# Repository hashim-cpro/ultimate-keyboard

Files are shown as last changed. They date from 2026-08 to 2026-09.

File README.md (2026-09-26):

# Ultimate-keyboard

A custom **75% (84-key)** mechanical keyboard built from the ground up with **Bluetooth 5.0 wireless & wired USB-C connectivity**, **individually addressable per-key RGB backlighting**, **Kailh MX hot-swap sockets**, and **integrated LiPo battery charging**.

It uses the [nrfmicro](https://github.com/joric/nrfmicro) microcontroller architecture as inspiration. Basically, instead of soldering a separate development board onto the keyboard, I copied the microcontroller schematics, put the **Nordic nRF52840 SoC** (via Ebyte E73 module) directly onto the keyboard's PCB, added battery charging and power management circuitry, and routed the entire PCB myself! At the end of the day, the IC lives right on the keyboard PCB with ample room to route everything cleanly.

---

## 3D Renders & Showcase

| Top View | Isometric Side View | Bottom View |
| :---: | :---: | :---: |
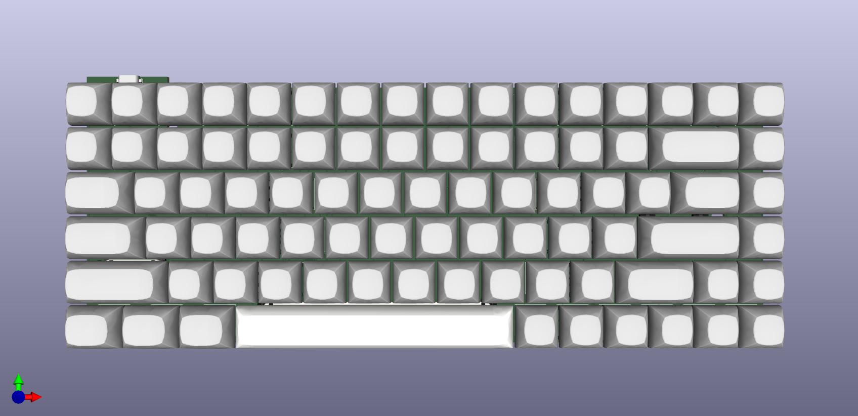
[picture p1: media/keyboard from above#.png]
Top View
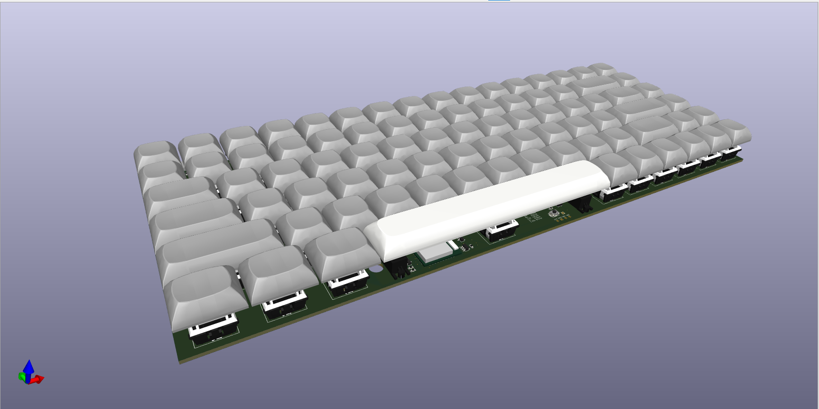
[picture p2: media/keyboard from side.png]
Side View
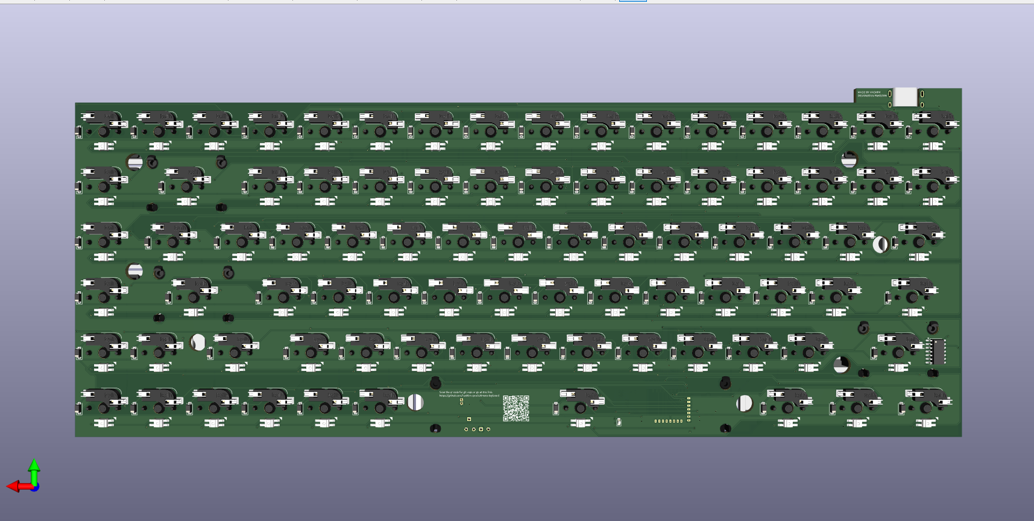
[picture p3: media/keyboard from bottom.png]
Bottom View
|  |  |  |

| PCB Top Layer | PCB Bottom Layer |
| :---: | :---: |
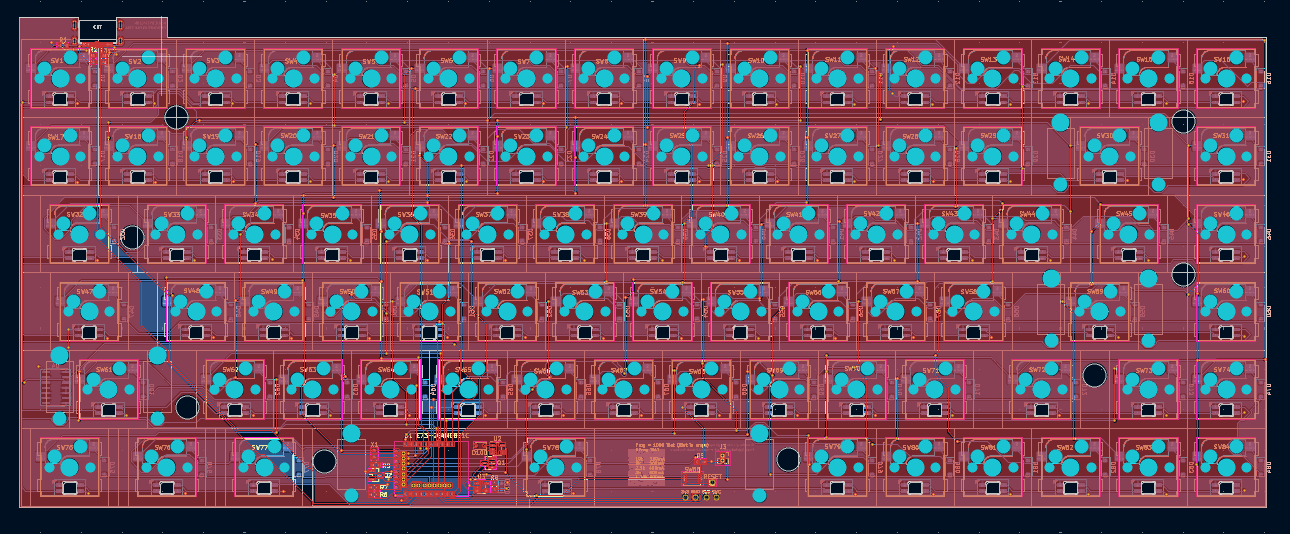
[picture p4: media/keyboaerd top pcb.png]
PCB Top
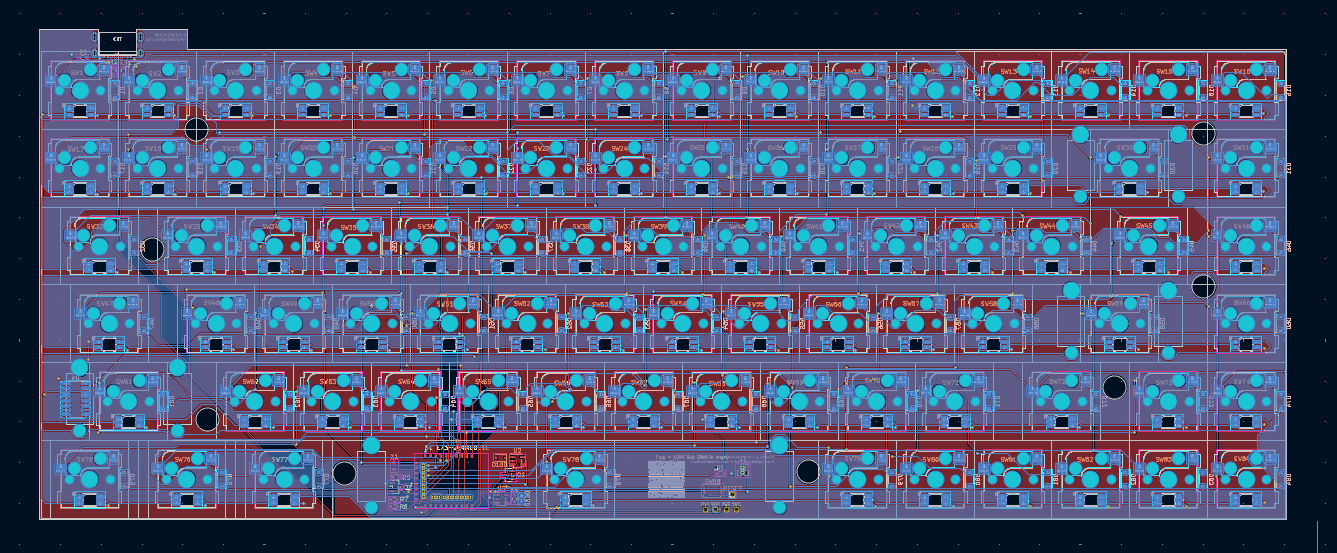
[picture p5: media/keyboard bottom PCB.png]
PCB Bottom
|  |  |

---

## Project Directory Map

```
ultimate-keyboard/
├── .github/
│   └── workflows/
│       └── build.yml               # Automated ZMK CI build workflow
├── boards/hashim/ultimate_keyboard/ # Zephyr HWMv2 board definition
│   ├── board.yml                   # Board metadata (SoC: nrf52840, variant: zmk)
│   ├── Kconfig.ultimate_keyboard   # Board selection & ZMK_BOARD_COMPAT
│   ├── Kconfig.defconfig           # Name & bootloader retention settings
│   ├── ultimate_keyboard.zmk.yml   # ZMK hardware metadata catalog
│   ├── ultimate_keyboard_nrf52840_zmk.dts # Devicetree definition (matrix, ADC, SPI RGB)
│   └── ultimate_keyboard_nrf52840_zmk_defconfig # Base Kconfig drivers
├── config/
│   ├── ultimate_keyboard.keymap    # 84-key QWERTY + Function layers
│   ├── ultimate_keyboard.conf      # Bluetooth TX power, sleep, RGB underglow
│   └── west.yml                    # Manifest
├── firmware/
│   ├── boards/hashim/ultimate_keyboard/ # Board definition mirror
│   ├── config/                     # Keymap and config mirror
│   ├── build.yaml                  # Firmware build matrix
│   └── ultimate_keyboard.uf2       # Compiled functional flash file (ready to flash)
├── hardware/
│   ├── nrfmicro.kicad_sch
│   ├── nrfmicro.kicad_pcb
│   ├── nrfmicro.kicad_pro
├── exports/
│   ├── gerbers.zip
│   └── others/
│       ├── nrfmicro.csv
│       ├── nrfmicro.step
│       └── nrfmicro board.step
├── media/
├── build.yaml
├── keyboard-layout.json
├── upper plate.dxf
├── journal.md
└── README.md
```

---

## Bill of Materials (BOM)

### 1. Integrated Circuits & Semiconductors

| Designator | Value / Part | Package / Footprint | Qty | Description |
| :--- | :--- | :--- | :-: | :--- |
| U1 | **[E73-2G4M08S1C](https://www.ebyte.com/en/product-view-news.html?id=445)** | E73-2G4M08S1C-52840 |  1  | Nordic nRF52840 Bluetooth 5.0 & USB 2.0 SoC Module with PCB Antenna |
| U2 | **[AP2112K-3.3](https://lcsc.com/product-detail/Low-Dropout-Regulators-LDO_Diodes-Incorporated-AP2112K-3-3TRG1_C51118.html)** | SOT-23-5 |  1  | 3.3V 600mA Ultra-Low Dropout (LDO) Linear Voltage Regulator |
| U3 | **[TP4054](https://lcsc.com/product-detail/Battery-Management-ICs_TP4054_C32574.html)** | SOT-23-5 |  1  | Standalone Linear Li-Ion Battery Charger IC |
| U4 | **[74AHCT125](https://lcsc.com/product-detail/Buffers-Drivers-Receivers-Transceivers_Nexperia-74AHCT125D-118_C137151.html)**  | SOIC-14 (3.9x8.7mm, P1.27mm) |  1  | Quad Buffer / 3.3V to 5V Logic Level Shifter for RGB LEDs |
| Q1, Q2 | **[AO3407](https://lcsc.com/product-detail/MOSFETs_Alpha-Omega-Semicon-AO3407_C13184.html)** | SOT-23 |  2  | P-Channel 30V MOSFET (Power path switching & battery reverse protection) |
| D100 | **[1N5819](https://lcsc.com/product-detail/Schottky-Barrier-Diodes-SBD_1N5819W_C169344.html)** | D_SOD-323F |  1  | Schottky Barrier Rectifier Diode (Power OR-ing) |
| D200 | **RED LED** | LED_0603_1608Metric |  1  | Red 0603 SMD LED (Battery charge indicator) |

### 2. Key Matrix Diodes & Addressable RGB LEDs

| Designator | Value / Part | Package / Footprint | Qty | Description |
| :--- | :--- | :--- | :-: | :--- |
| D1 – D84 | **[1N4148WT](https://lcsc.com/product-detail/Switching-Diodes_1N4148W_C2128.html)** | D_SOD-123 | 84  | High-Speed Switching Diodes (Anti-Ghosting / NKRO Matrix) |
| LED1 – LED84 | **[SK6812MINI-E](https://lcsc.com/product-detail/Light-Emitting-Diodes-LED_HOUEN-SK6812MINI-E_C2890035.html)** | MX_SK6812MINI-E_REV | 84  | Reverse-Mount Individually Addressable RGB LEDs |

### 3. Kailh MX Hot-Swap Sockets

| Designator | Key Size | Footprint |  Qty | Target Keys |
| :--- | :---: | :--- | :----: | :--- |
| SW2, SW29, ... | **[1.00u Socket](https://www.aliexpress.com/w/wholesale-kailh-hot-swap-socket.html)** | SW_Hotswap_Kailh_MX_1.00u | 73 | Standard 1u Alpha, Number, Function & Navigation keys |
| SW75, SW76, SW77  | **1.25u Socket** | SW_Hotswap_Kailh_MX_1.25u | 3 | Left Ctrl, Left Win, Left Alt |
| SW45, SW32 | **1.50u Socket** | SW_Hotswap_Kailh_MX_1.50u | 2 | Tab, Backslash (\|) |
| SW47, SW72 | **1.75u Socket** | SW_Hotswap_Kailh_MX_1.75u | 2 | Caps Lock, Right Shift |
| SW30 | **2.00u Socket** | SW_Hotswap_Kailh_MX_2.00u | 1 | Backspace |
| SW59, SW61 | **2.25u Socket** | SW_Hotswap_Kailh_MX_2.25u | 2 | Left Shift, Enter |
| SW78 | **6.25u Socket** | SW_Hotswap_Kailh_MX_6.25u | 1 | Spacebar |
| **Total Sockets** | | | **84** | Full 75% layout coverage |

### 4. Connectors, Switches & Crystal

| Designator | Value / Part | Package / Footprint | Qty | Description |
| :--- | :--- | :--- | :-: | :--- |
| J1 | **[USB-C Receptacle 16-pin](https://lcsc.com/product-detail/USB-Connectors_SHOU-HAN-TYPE-C-16PIN_C319133.html)** | USB-C_C168688 |  1  | USB Type-C Receptacle (16-Pin) |
| J2 | **Conn_01x04** | connector_swd |  1  | 4-Pin SWD Header (VDD, SWDIO, SWCLK, GND) |
| J3 | **Conn_01x02** | PinSocket_1x02_P1.27mm_Vertical |  1  | 2-Pin Battery Header (for LiPo battery) |
| SW85 | **[Tactile Switch](https://lcsc.com/product-detail/Tactile-Switches_ALPS-ALPINE-SKRK-series_C2665793.html)** | SW_Push_SPST_NO_Alps_SKRK |  1  | Tactile Push Button (Reset / Bootloader mode) |
| RESET | **TestPoint** | TestPoint_THTPad_1.0x1.0mm_Drill0.5mm |  1  | Hardware Reset Test Point |
| X1 | **[32.768kHz Crystal](https://lcsc.com/product-detail/Crystals_Micro-Crystal-Switzerland-CM9V-T1A-32-768kHz-7pF-20PPM-TA-QC_C347311.html)** | CM9V-T1A-2Pin_1.6x1.0mm |  1  | MicroCrystal CM9V-T1A low-frequency crystal for BLE sleep mode |

### 5. Resistors (SMD 0603)

| Designator | Value | Footprint | Qty | Function / Notes |
| :--- | :---: | :--- | :-: | :--- |
| R1 | **100kΩ** | R_0603_1608Metric |  1  | Pull-up / Gate bias resistor |
| R2, R3 | **5.1kΩ** | R_0603_1608Metric |  2  | USB Type-C CC1 / CC2 pull-down resistors (5V host negotiation) |
| R5 | **RPROG** | R_0603_1608Metric |  1  | Charge current setting resistor for TP4054 |
| R6 | **820kΩ** | R_0603_1608Metric |  1  | Voltage divider bias resistor |
| R7, R9 |  **2MΩ**  | R_0603_1608Metric |  2  | High-impedance battery voltage monitoring divider |
| R8 |  **1kΩ**  | R_0603_1608Metric |  1  | Current limiting resistor for indicator LED |

---

## Wiring Diagram

Completed wiring diagram
see in [pdf](/exports/diagrams/keyboard_wiring_diagram.pdf)

## Schematics

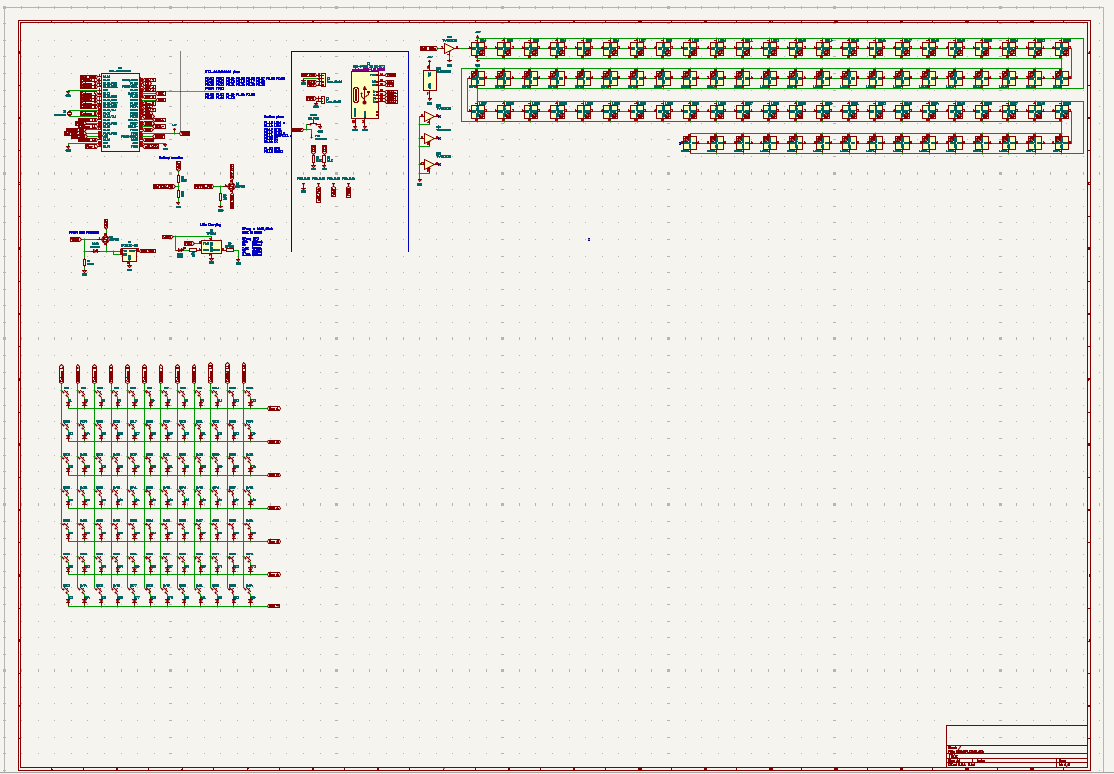
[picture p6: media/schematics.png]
Completed Schematic


## Firmware (ZMK)

The keyboard runs native [ZMK Firmware](https://zmk.dev/) built on the Zephyr RTOS with full support for Bluetooth Low Energy 5.0, USB HID, low-power deep sleep, battery level telemetry, and individually addressable RGB backlighting.

A pre-compiled, tested, ready-to-flash binary is available at: **[`firmware/ultimate_keyboard.uf2`](firmware/ultimate_keyboard.uf2)**

## How to Build the Firmware

### GitHub Actions (Recommended & Automated)

This repository includes a GitHub Actions workflow in [`.github/workflows/build.yml`](.github/workflows/build.yml) configured with ZMK's official build matrix. Every push to `main` automatically triggers a build in the cloud.

1. Edit your keymap in [`config/ultimate_keyboard.keymap`](config/ultimate_keyboard.keymap) or settings in [`config/ultimate_keyboard.conf`](config/ultimate_keyboard.conf).
2. Commit and push your changes:
3. Once the workflow run completes, click into the run, scroll to **Artifacts**, and download `ultimate_keyboard.zip`.
4. Extract the `.uf2` file and flash it!
   > (enter bootloader mode by holding the dedicated button beneath space bar)

---

## Assembly

After getting the PCB and the components, you can assemble the keyboard by following these steps:

- first of all solder the MCU and the ICs surrounding it on the top side of the PCB with a heat gun.
- then solder the usbc port and the boot button and the battery connections header(you can solder the wires directly to the pads if you want).
- then solder the diodes, rgb leds and switch sockets along with everything remaining on the bottom side of the PCB.
- connect the battery, flash the firmware, put the switches in and then you can test the keyboard and make sure everything is working properly.

---

### AI Usage Declaration

I used AI for research, general queries and for asking question like using it instead of google, and formatting the markdown documentation and BOM tables. and fixing firmware as well.

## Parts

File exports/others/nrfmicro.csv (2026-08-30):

Id | Designator | Footprint | Quantity | Designation | Supplier and ref
1 | RESET | TestPoint_THTPad_1.0x1.0mm_Drill0.5mm | 1 | TestPoint
2 | J2 | connector_swd | 1 | Conn_01x04
3 | SW85 | SW_Push_SPST_NO_Alps_SKRK | 1 | SW_Push
4 | X1 | Crystal_SMD_MicroCrystal_CM9V-T1A-2Pin_1.6x1.0mm_HandSoldering | 1 | 32768kHz
5 | U3 | SOT-23-5 | 1 | TP4054
6 | LED39,LED18,LED61,LED21,LED58,LED48,LED5,LED14,LED80,LED63,LED74,LED6,LED1,LED81,LED43,LED12,LED57,LED44,LED2,LED79,LED62,LED41,LED17,LED69,LED68,LED76,LED46,LED28,LED23,LED24,LED9,LED33,LED55,LED4,LED38,LED82,LED70,LED11,LED19,LED15,LED47,LED10,LED50,LED84,LED8,LED42,LED7,LED20,LED49,LED71,LED75,LED66,LED34,LED65,LED59,LED54,LED31,LED30,LED35,LED26,LED25,LED27,LED67,LED83,LED22,LED78,LED72,LED16,LED3,LED53,LED32,LED56,LED60,LED37,LED36,LED29,LED45,LED52,LED51,LED77,LED13,LED40,LED64,LED73 | MX_SK6812MINI-E_REV | 84 | SK6812MINI-E
7 | R8 | R_0603_1608Metric | 1 | 1K
8 | SW2,SW29,SW9,SW4,SW21,SW53,SW74,SW13,SW41,SW5,SW63,SW10,SW1,SW39,SW79,SW70,SW48,SW43,SW35,SW34,SW66,SW26,SW71,SW40,SW62,SW56,SW44,SW38,SW27,SW67,SW64,SW3,SW82,SW80,SW81,SW23,SW42,SW18,SW46,SW28,SW19,SW8,SW11,SW33,SW65,SW51,SW17,SW36,SW37,SW57,SW83,SW25,SW50,SW6,SW68,SW20,SW31,SW84,SW55,SW22,SW58,SW14,SW24,SW73,SW16,SW69,SW60,SW7,SW54,SW12,SW15,SW52,SW49 | SW_Hotswap_Kailh_MX_1.00u | 73 | SW_Push_45deg
9 | SW45,SW32 | SW_Hotswap_Kailh_MX_1.50u | 2 | SW_Push_45deg
10 | R5 | R_0603_1608Metric | 1 | RPROG
11 | Q2,Q1 | SOT-23 | 2 | AO3407
12 | SW47,SW72 | SW_Hotswap_Kailh_MX_1.75u | 2 | SW_Push_45deg
13 | R6 | R_0603_1608Metric | 1 | 820K
14 | SW75,SW77,SW76 | SW_Hotswap_Kailh_MX_1.25u | 3 | SW_Push_45deg
15 | U2 | SOT-23-5 | 1 | AP2112K-3.3
16 | J1 | USB-C_C168688 | 1 | USB-C USB 2.0 MC-372
17 | R3,R2 | R_0603_1608Metric | 2 | 5.1K
18 | SW59,SW61 | SW_Hotswap_Kailh_MX_2.25u | 2 | SW_Push_45deg
19 | R9,R7 | R_0603_1608Metric | 2 | 2M
20 | R1 | R_0603_1608Metric | 1 | 100K
21 | SW30 | SW_Hotswap_Kailh_MX_2.00u | 1 | SW_Push_45deg
22 | U1 | E73-2G4M08S1C-52840 | 1 | E73-2G4M08S1C
23 | J3 | PinSocket_1x02_P1.27mm_Vertical | 1 | Conn_01x02
24 | D100 | D_SOD-323F | 1 | 1N5819
25 | SW78 | SW_Hotswap_Kailh_MX_6.25u | 1 | SW_Push_45deg
26 | D16,D39,D62,D11,D68,D49,D75,D61,D69,D83,D55,D72,D44,D53,D27,D36,D4,D43,D9,D21,D30,D19,D17,D66,D48,D22,D10,D58,D84,D38,D82,D79,D52,D13,D54,D41,D45,D47,D35,D3,D80,D51,D29,D6,D81,D28,D23,D24,D57,D26,D64,D37,D63,D70,D1,D32,D25,D74,D12,D34,D77,D71,D8,D15,D5,D78,D18,D50,D40,D60,D14,D67,D33,D73,D7,D20,D2,D31,D76,D46,D59,D42,D56,D65 | D_SOD-123 | 84 | 1N4148WT
27 | U4 | SOIC-14_3.9x8.7mm_P1.27mm | 1 | 74AHCT125
28 | D200 | LED_0603_1608Metric | 1 | RED

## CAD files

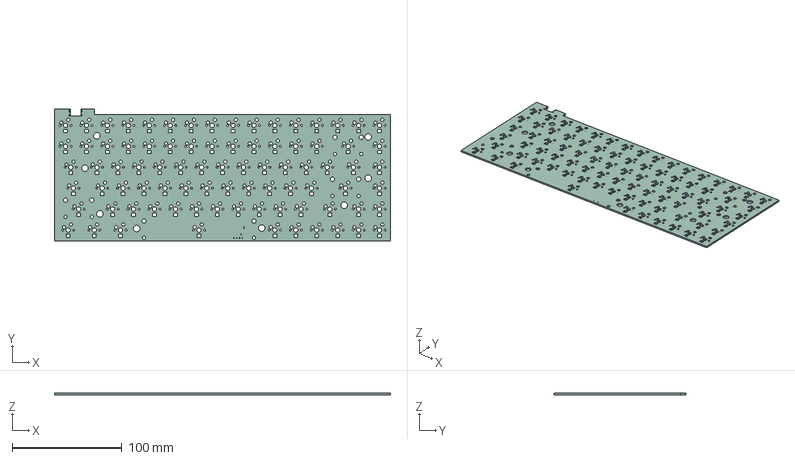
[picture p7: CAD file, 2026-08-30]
exports/others/nrfmicro board.step
305.8 x 120.2 x 1.51 mm

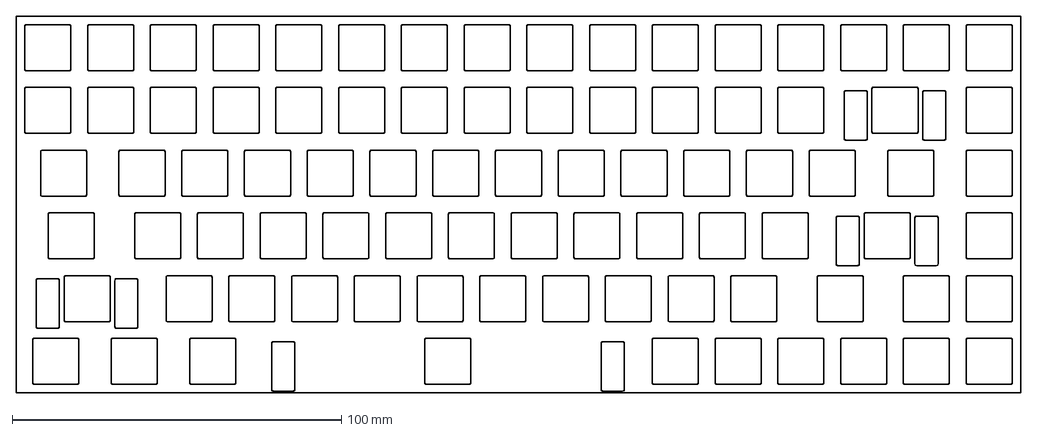
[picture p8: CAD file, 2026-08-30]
upper plate.dxf
304.8 x 114.3 mm

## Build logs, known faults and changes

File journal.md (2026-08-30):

---
title: "ultimate keyboard"
author: "Hashim"
description: "Dev journal for designing the ultimate 84-key wireless mechanical keyboard with onboard nRF52840, hot-swap sockets, and per-key RGB."
created_at: "July 8, 2026"
software: "KiCad, FreeCAD, ZMK"
---

# July 21: Researching for the ultimate keyboard

So i did some researching and basically what i want from this keyboard is a couple of things.

- has to be wireless
- needs to have multiple device connectivity and instant switching between them
- needs to have a good battery life
- hot swappable keys
- indiviidualy addressable RGB lghting

First thing that i want to do is decide the microcontroller for it supported by ZMK. ZMK could support basically any mcrocontroller that has the supporte microchip set but they recommended using some open source microcontrollers that are supported by the community. I took a look at some and decided why use a prebuilt microcontroller and why not just use the opensource microcontroller's schematics and put em on my keyboard and we would have ample PCB space because a keyboard is pretty big so why not just expand the microcontroller on the keyboard itself, what i am saying is use the microcontroller's schematics and put it on the keyboard's PCB and route it myself and place the components where ever i want to.

the microcontroller i choosed is [this](https://github.com/joric/nrfmicro):

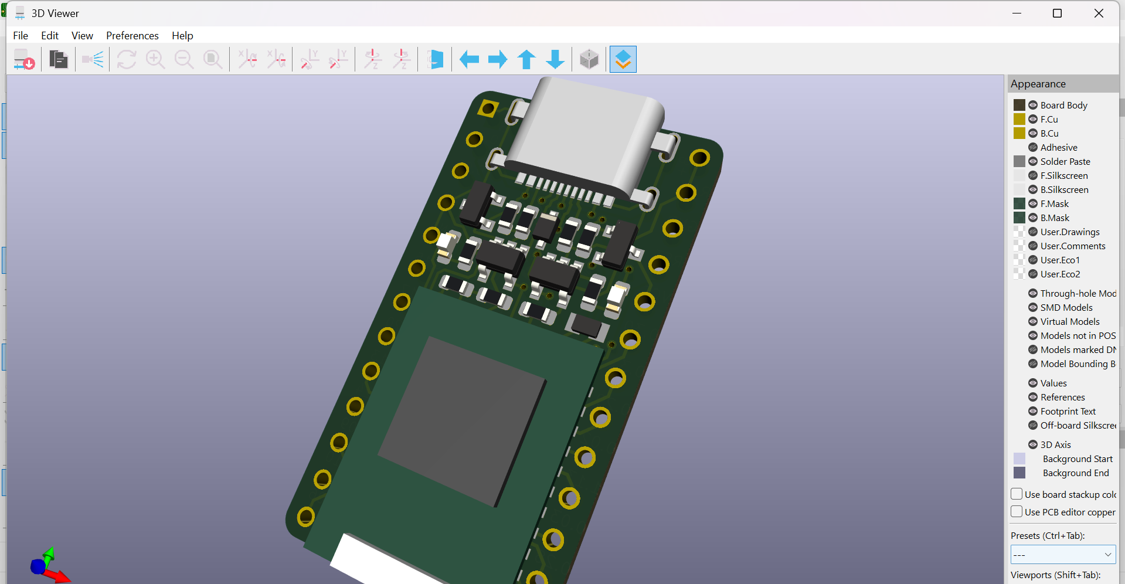
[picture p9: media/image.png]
nRFMicro Pinout


ok so started working on it, i would have a 84 keys keyboard. i first made the switch matrix closer to the actual shape of the keyboard layout but then somehow though we might not enough pins so ended up reverting it to this(but turns out we have more then enough pins, 28 to be precise)

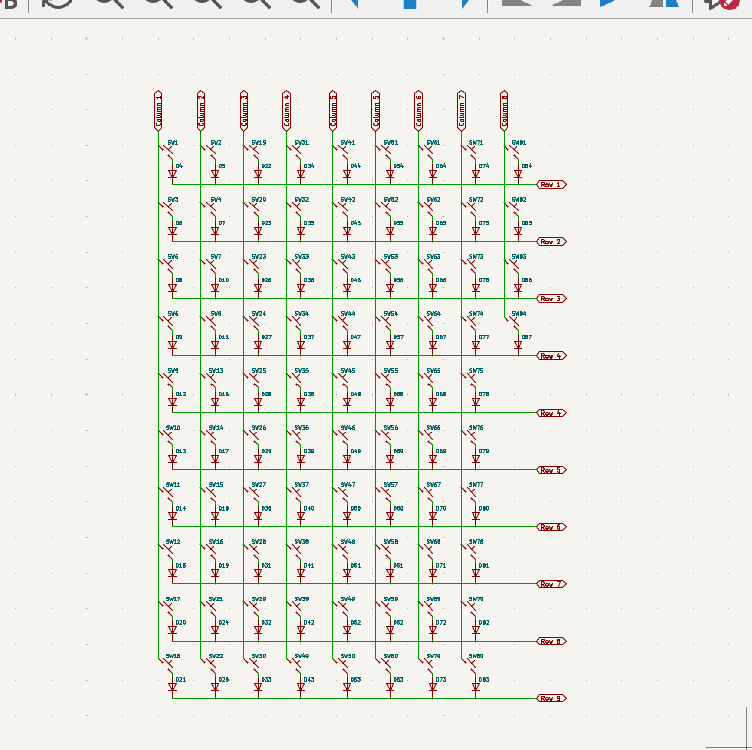
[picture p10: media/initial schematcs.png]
Initial Switch Matrix Schematic


Lapse session: https://lapse.hackclub.com/timelapse/6FpUl1i0e8Nd

---

# Next day: Footprints, 3D Models & Schematics

i finished the schematics, and found and imported all the footrpints and their 3d models and placed them on the PCB exactly where i wanted them to be.

Completed Keyboard Schematics

Lapse link:
https://lapse.hackclub.com/timelapse/ch_FO-Pfzgz0

---

# Next day: PCB Routing

i started routing the PCB, and it was a bit of a challenge because i had to route the microcontroller's pins to the switch matrix and also to the other components like the battery, charging circuit, and RGB lighting. But after a few hours of routing, i managed to get everything connected properly.

| Top PCB Routing | Bottom PCB Routing |
|:---:|:---:|
| Keyboard Top PCB | Keyboard Bottom PCB |

Lapse link:
https://lapse.hackclub.com/timelapse/OkOtTtODVTxe

---

# Next day: Mounting Holes & Bootloader Circuitry

added mounting holes, remaining stuff added related to bootloader and frmware flashing
i added circuitry for the bootloading thing and added a button for it

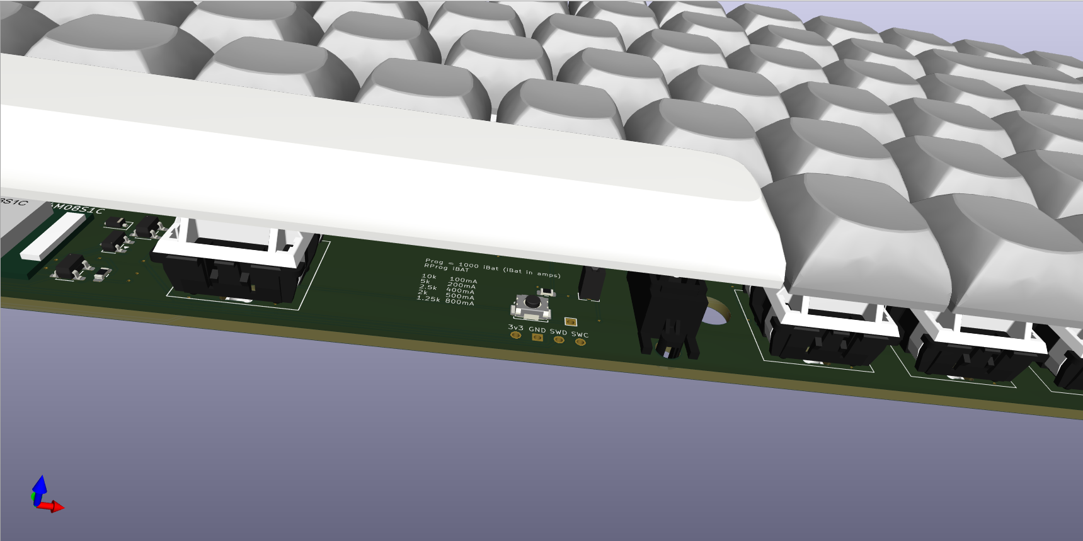
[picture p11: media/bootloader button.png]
Bootloader and Reset Button Circuitry


Lapse link:
https://lapse.hackclub.com/timelapse/6yTGAWsrufwA

---

# Next day: Case Modeling & Optimization

tried to start making a case
file was apparently too big and had to do a lot of isolations and optimization to keep it from crashing on my 4 gb ipad
so i just thought i show here what's that was made and make the case a separate project.

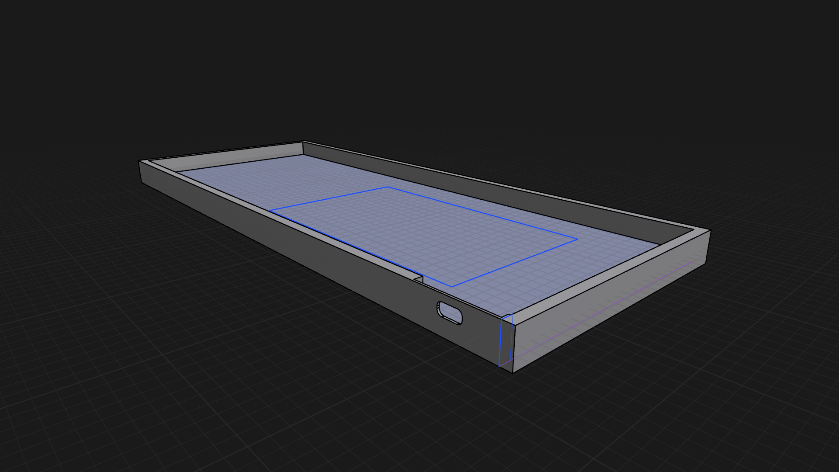
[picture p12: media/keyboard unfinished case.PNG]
Unfinished Keyboard Case


Lapse link:
https://lapse.hackclub.com/timelapse/ksh1qt40XOUj

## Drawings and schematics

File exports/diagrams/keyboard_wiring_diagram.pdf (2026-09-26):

# ULTIMATE KEYBOARD 75% — COMPLETE PHYSICAL WIRING DIAGRAM

Photorealistic 3D Component Breakout & Manhattan Orthogonal Matrix Wiring • Generated from hardware/nrfmicro.kicad_pcb

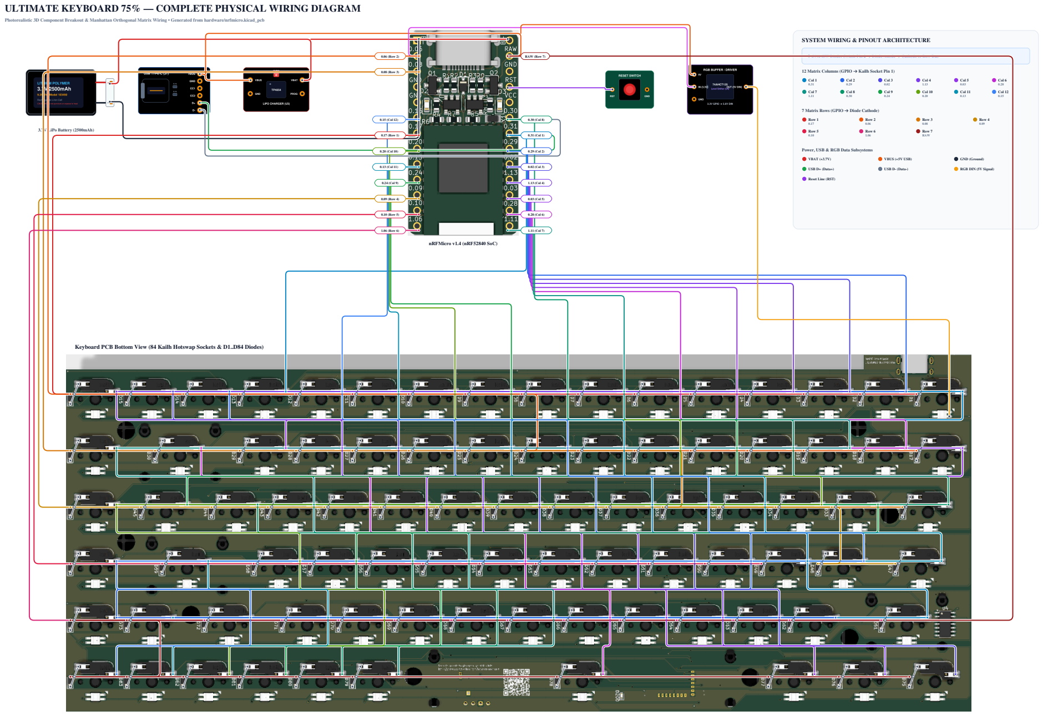
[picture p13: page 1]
3.7V LiPo Battery (2500mAh); nRFMicro v1.4 (nRF52840 SoC); Col 2 0.29; Col 3 0.02; Col 4 1.13; Col 5 0.03; Col 6 0.28; Col 8 0.30; Col 9 0.24; Col 10 0.20; Col 11 0.13; Col 12 0.15; 7 Matrix Rows (GPIO ➔ Diode Cathode); Row 1 0.17; Row 2 0.06; Row 3 0.08; Row 4 0.09; Row 5 0.10; Row 6 1.06; Row 7 RAW; VBAT (+3.7V); VBUS (+5V USB); GND (Ground); USB D+ (Data+); USB D- (Data-); RGB DIN (5V Signal); 0.17 (Row 1); 0.06 (Row 2); 0.08 (Row 3); 0.09 (Row 4); 0.10 (Row 5); 1.06 (Row 6); RAW (Row 7)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

SYSTEM WIRING & PINOUT ARCHITECTURE

⬇ 1N4148W Diode: Switch Pin 2 ➔ Diode Anode ➔ Cathode to Row Bus

12 Matrix Columns (GPIO ➔ Kailh Socket Pin 1)
Col 1
Col 7

Power, USB & RGB Data Subsystems

Reset Line (RST)

Keyboard PCB Bottom View (84 Kailh Hotswap Sockets & D1..D84 Diodes)

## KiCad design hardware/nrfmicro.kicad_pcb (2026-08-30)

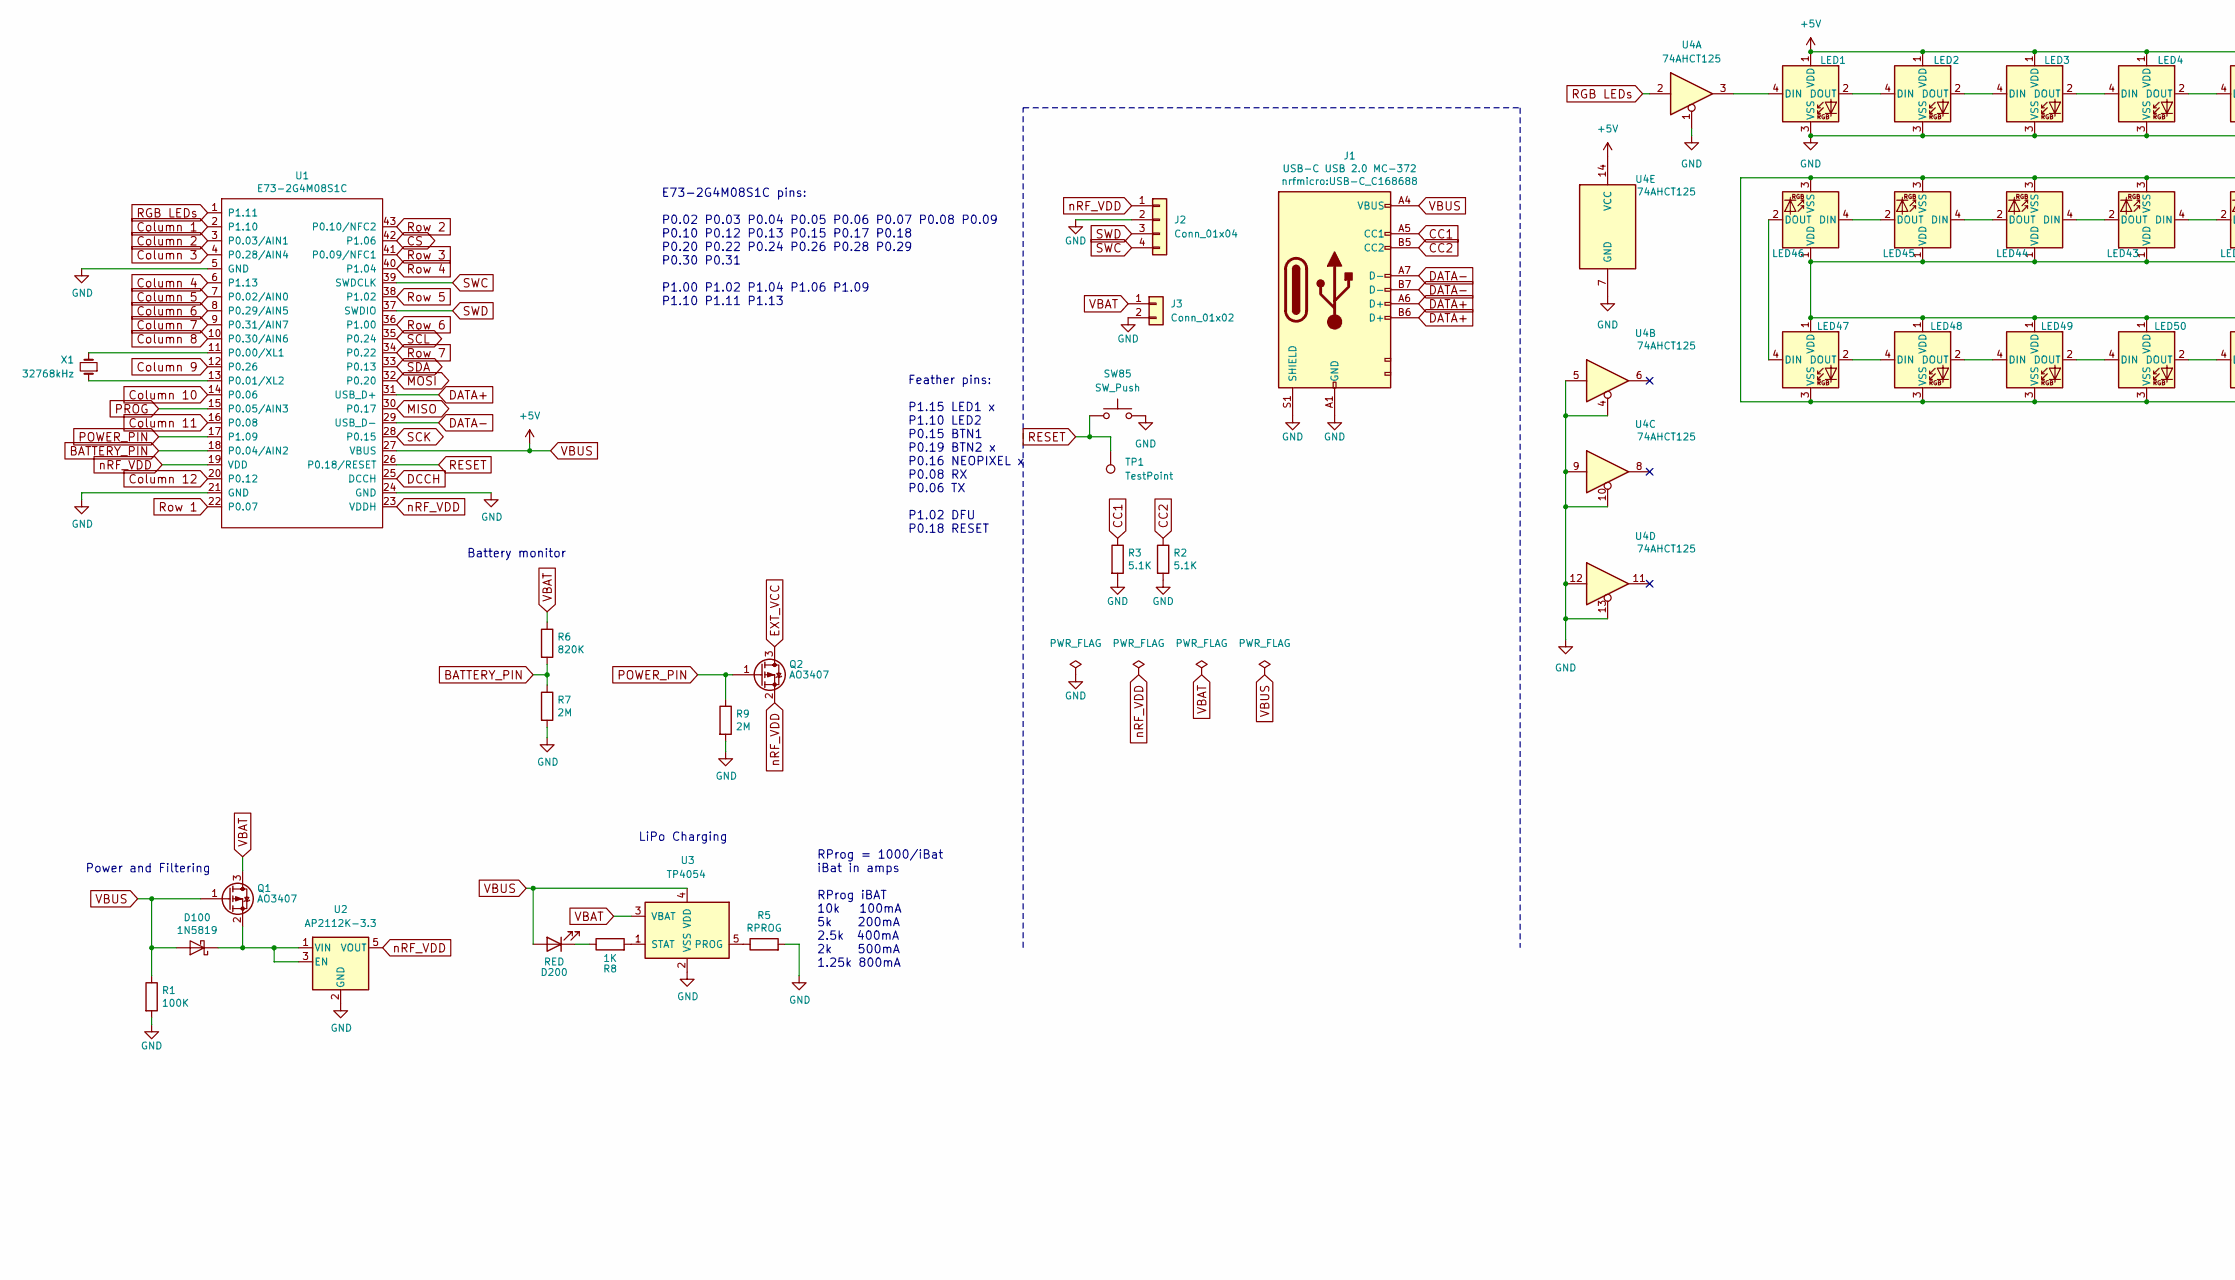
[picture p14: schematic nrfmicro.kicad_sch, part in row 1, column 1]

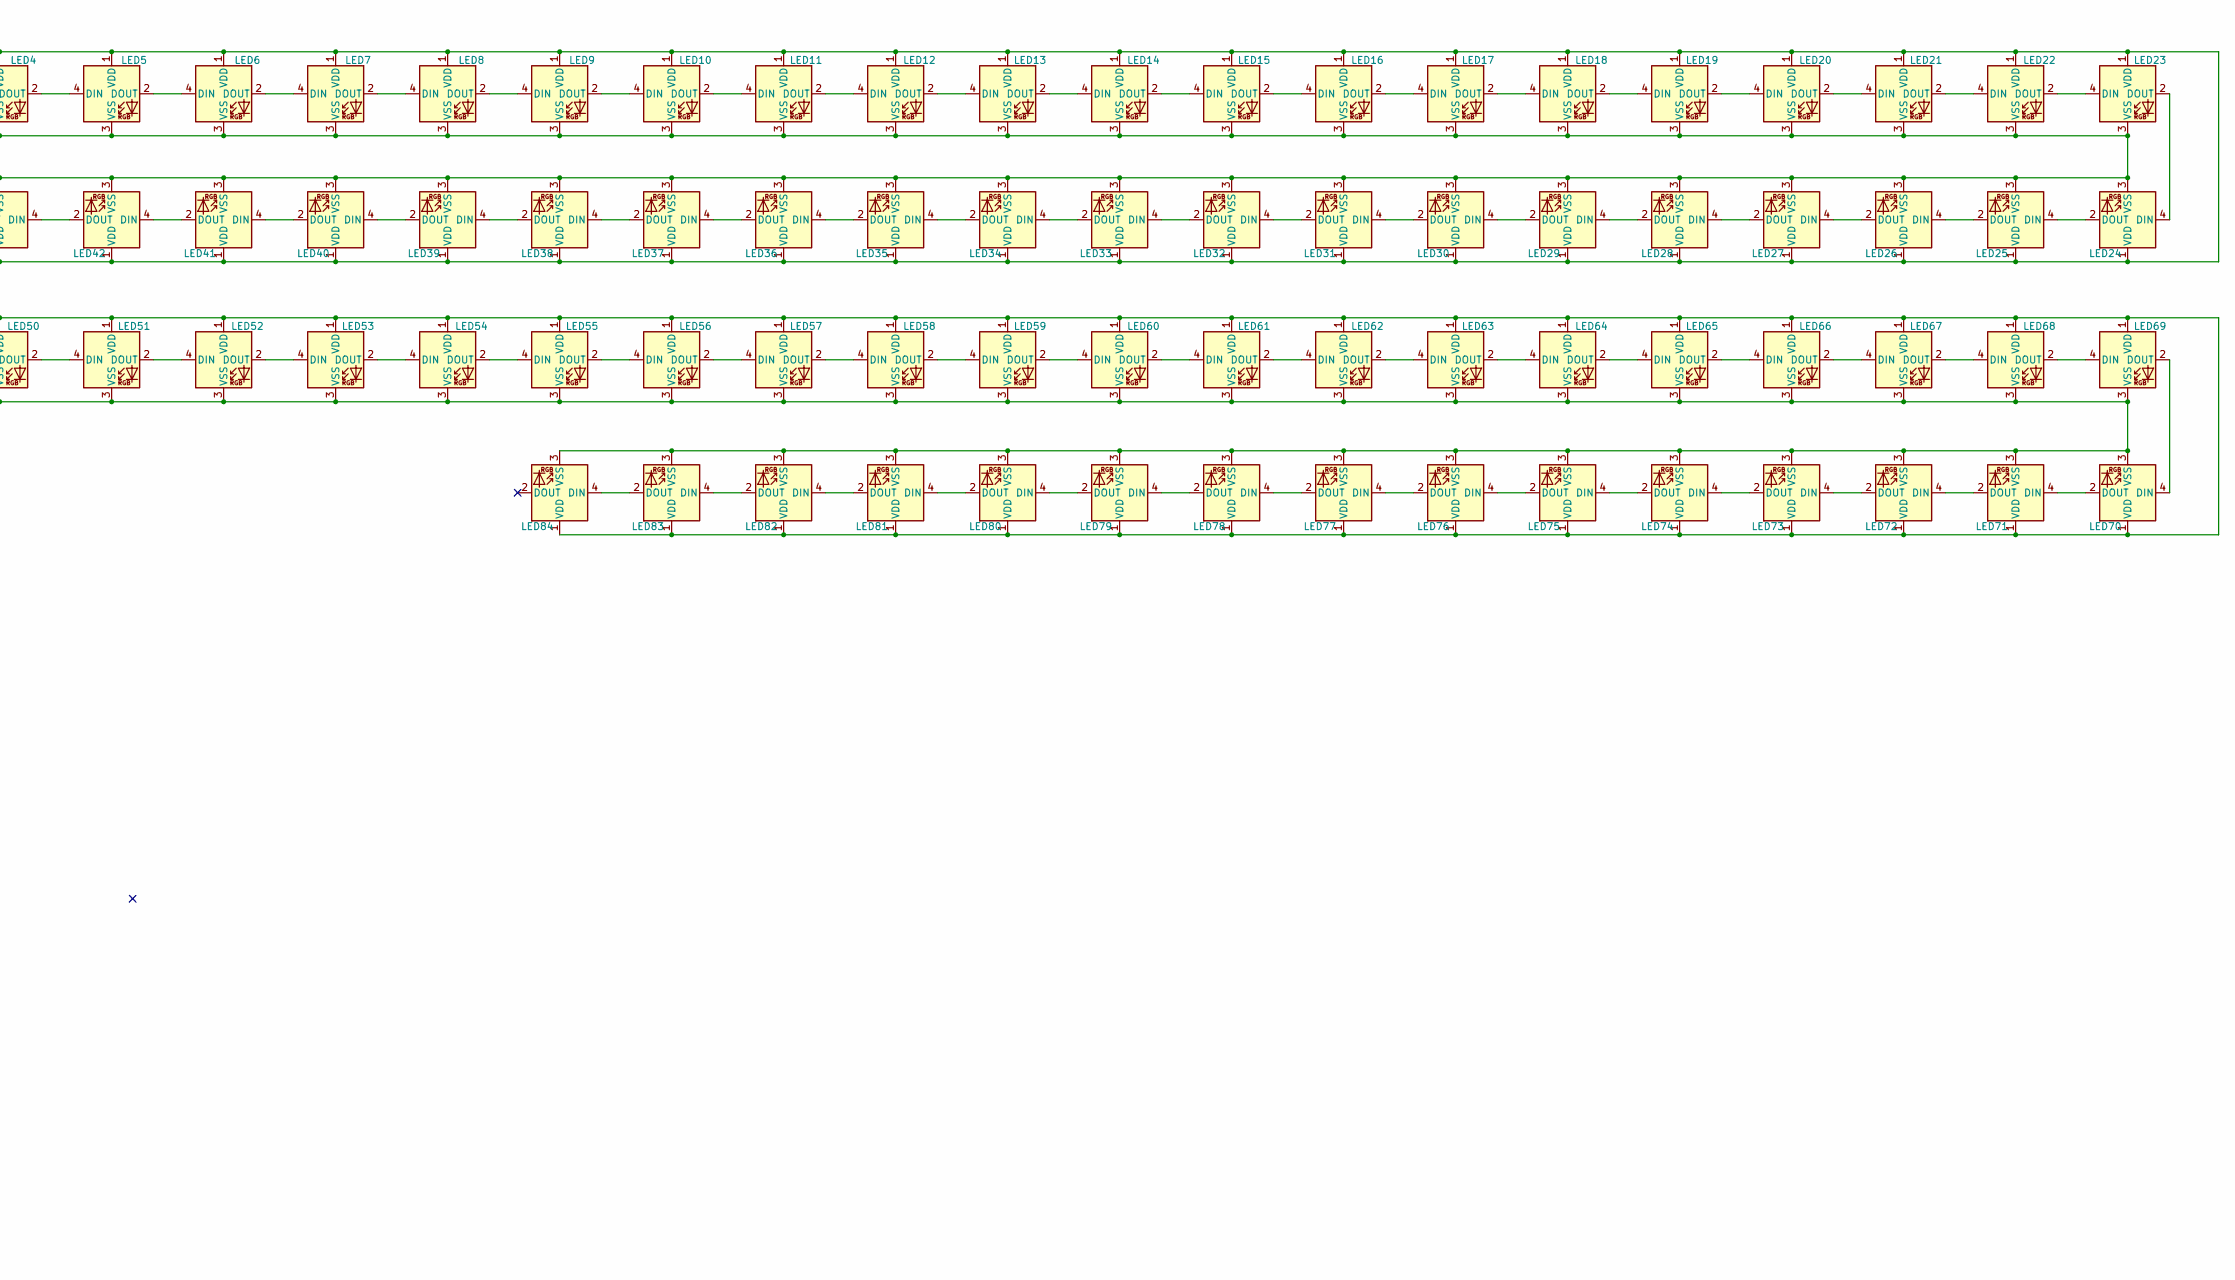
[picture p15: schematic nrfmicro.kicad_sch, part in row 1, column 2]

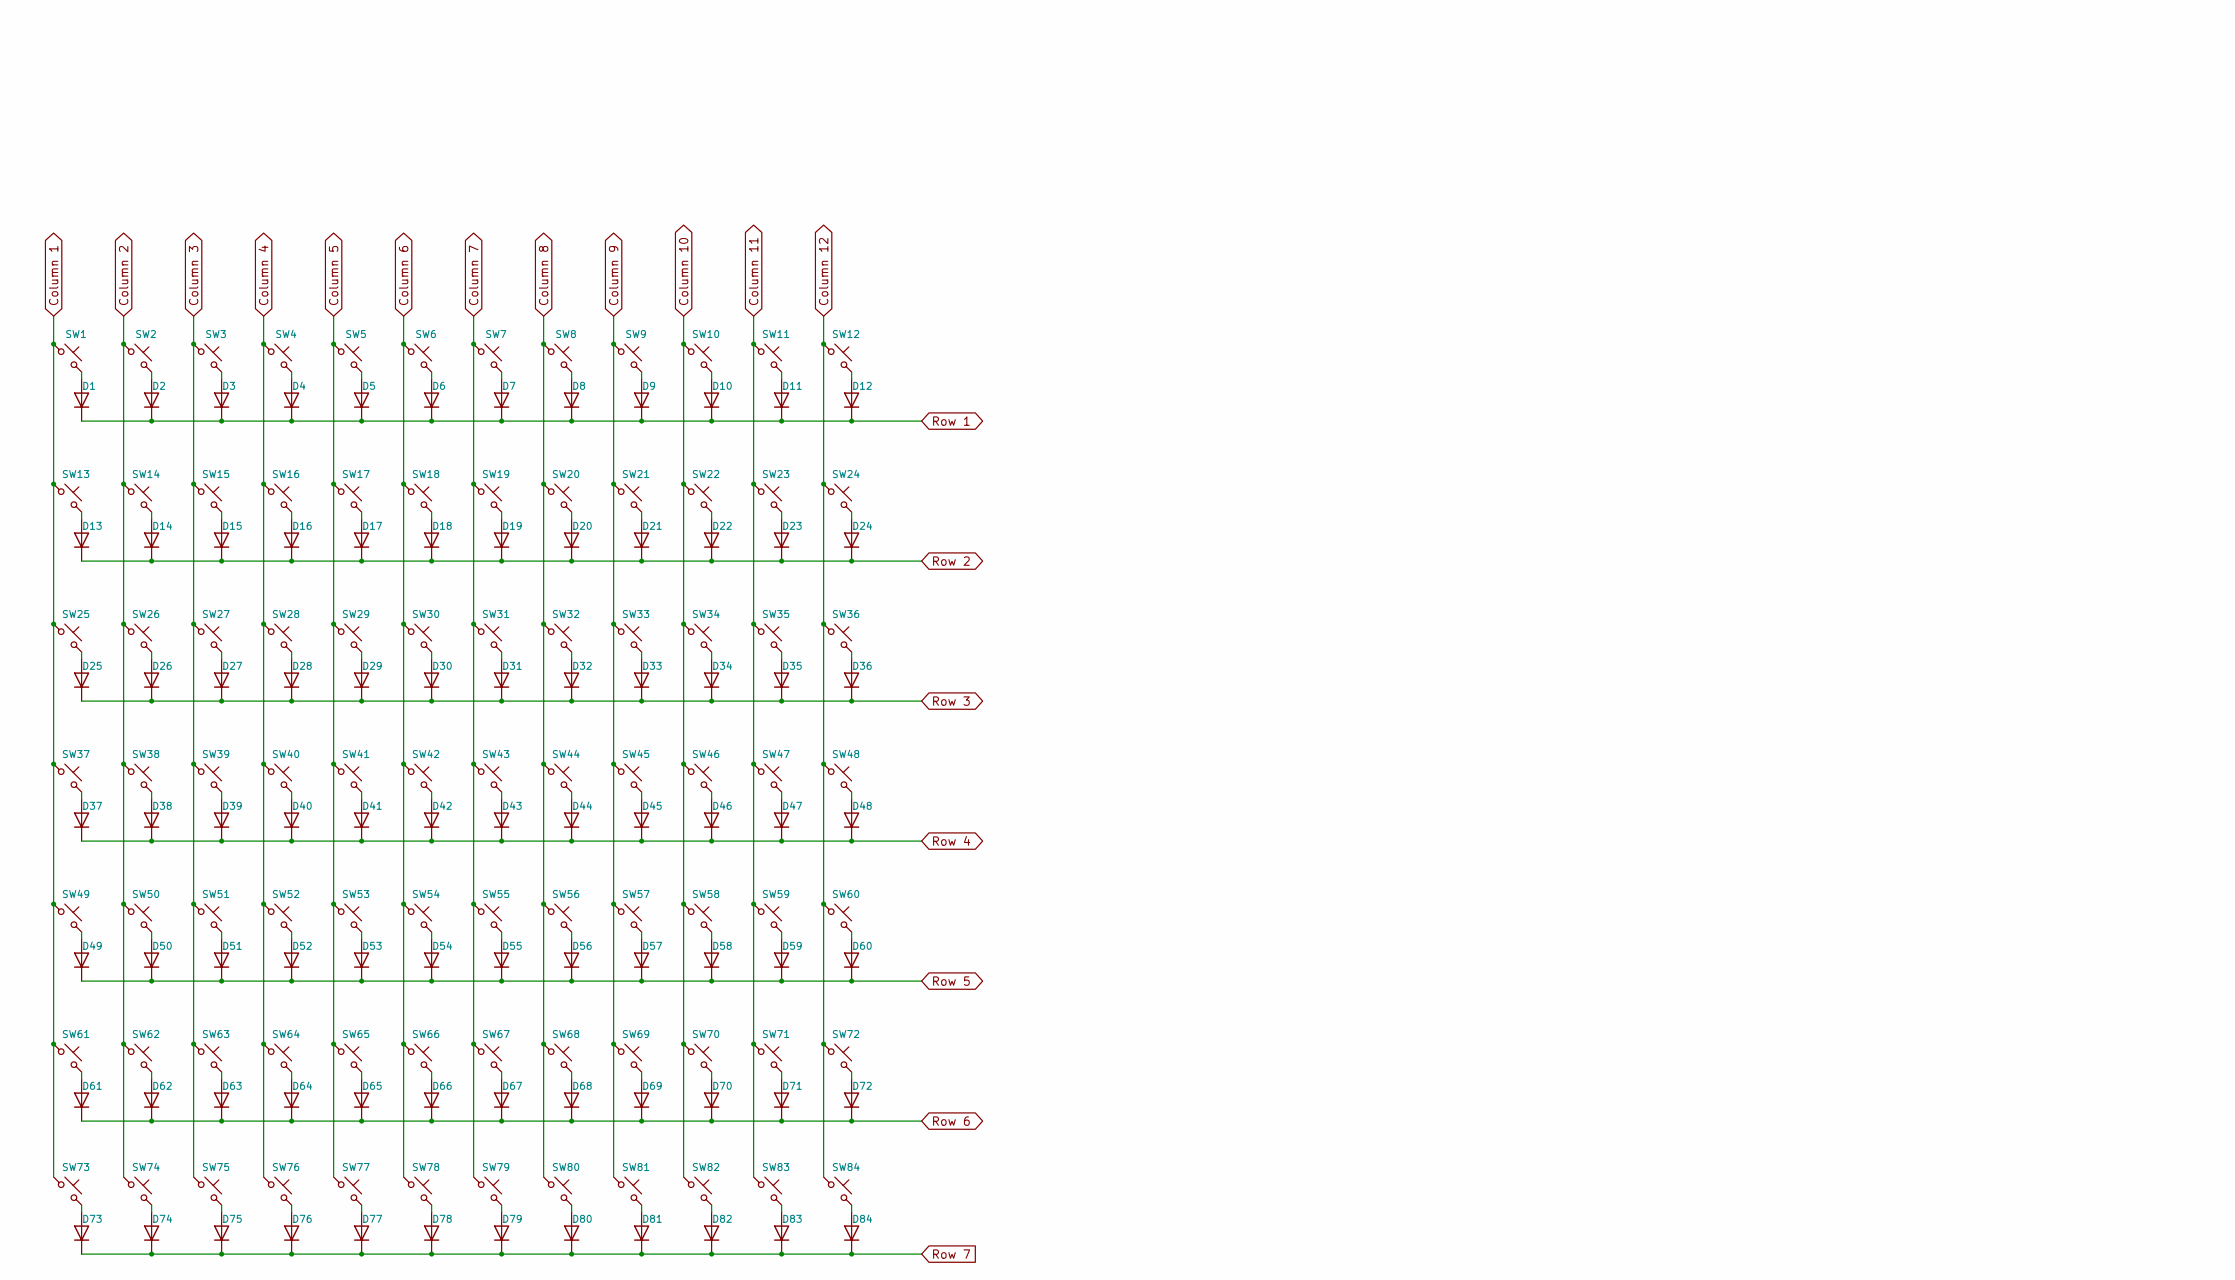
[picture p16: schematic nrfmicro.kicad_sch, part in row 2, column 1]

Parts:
D1, D2, D3, D4, D5, D6, D7, D8, D9, D10, D11, D12, D13, D14, D15, D16, D17, D18, D19, D20, D21, D22, D23, D24, D25, D26, D27, D28, D29, D30, D31, D32, D33, D34, D35, D36, D37, D38, D39, D40, D41, D42, D43, D44, D45, D46, D47, D48, D49, D50, D51, D52, D53, D54, D55, D56, D57, D58, D59, D60, D61, D62, D63, D64, D65, D66, D67, D68, D69, D70, D71, D72, D73, D74, D75, D76, D77, D78, D79, D80, D81, D82, D83, D84: 1N4148WT; D_SOD-123
D100: 1N5819; D_SOD-323F
D200: RED; LED_0603_1608Metric
J1: USB-C USB 2.0 MC-372; USB-C_C168688
J2: Conn_01x04; connector_swd
J3: Conn_01x02; PinSocket_1x02_P1.27mm_Vertical
LED1, LED2, LED3, LED4, LED5, LED6, LED7, LED8, LED9, LED10, LED11, LED12, LED13, LED14, LED15, LED16, LED17, LED18, LED19, LED20, LED21, LED22, LED23, LED24, LED25, LED26, LED27, LED28, LED29, LED30, LED31, LED32, LED33, LED34, LED35, LED36, LED37, LED38, LED39, LED40, LED41, LED42, LED43, LED44, LED45, LED46, LED47, LED48, LED49, LED50, LED51, LED52, LED53, LED54, LED55, LED56, LED57, LED58, LED59, LED60, LED61, LED62, LED63, LED64, LED65, LED66, LED67, LED68, LED69, LED70, LED71, LED72, LED73, LED74, LED75, LED76, LED77, LED78, LED79, LED80, LED81, LED82, LED83, LED84: SK6812MINI-E; MX_SK6812MINI-E_REV
Q1, Q2: AO3407; SOT-23
R1: 100K; R_0603_1608Metric
R2, R3: 5.1K; R_0603_1608Metric
R5: RPROG; R_0603_1608Metric
R6: 820K; R_0603_1608Metric
R7, R9: 2M; R_0603_1608Metric
R8: 1K; R_0603_1608Metric
SW1, SW2, SW3, SW4, SW5, SW6, SW7, SW8, SW9, SW10, SW11, SW12, SW13, SW14, SW15, SW16, SW17, SW18, SW19, SW20, SW21, SW22, SW23, SW24, SW25, SW26, SW27, SW28, SW29, SW31, SW33, SW34, SW35, SW36, SW37, SW38, SW39, SW40, SW41, SW42, SW43, SW44, SW46, SW48, SW49, SW50, SW51, SW52, SW53, SW54, SW55, SW56, SW57, SW58, SW60, SW62, SW63, SW64, SW65, SW66, SW67, SW68, SW69, SW70, SW71, SW73, SW74, SW79, SW80, SW81, SW82, SW83, SW84: SW_Push_45deg; SW_Hotswap_Kailh_MX_1.00u
SW30: SW_Push_45deg; SW_Hotswap_Kailh_MX_2.00u
SW32, SW45: SW_Push_45deg; SW_Hotswap_Kailh_MX_1.50u
SW47, SW72: SW_Push_45deg; SW_Hotswap_Kailh_MX_1.75u
SW59, SW61: SW_Push_45deg; SW_Hotswap_Kailh_MX_2.25u
SW75, SW76, SW77: SW_Push_45deg; SW_Hotswap_Kailh_MX_1.25u
SW78: SW_Push_45deg; SW_Hotswap_Kailh_MX_6.25u
SW85: SW_Push; SW_Push_SPST_NO_Alps_SKRK
TP1: TestPoint; TestPoint_THTPad_1.0x1.0mm_Drill0.5mm
U1: E73-2G4M08S1C; E73-2G4M08S1C-52840
U2: AP2112K-3.3; SOT-23-5
U3: TP4054; SOT-23-5
U4: 74AHCT125; SOIC-14_3.9x8.7mm_P1.27mm
X1: 32768kHz; Crystal_SMD_MicroCrystal_CM9V-T1A-2Pin_1.6x1.0mm_HandSolder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

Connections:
BATTERY_PIN: R6.2, R7.1, U1.18 (P0.04/AIN2)
CC1: J1.A5 (CC1), R3.1
CC2: J1.B5 (CC2), R2.1
CS: U1.42 (P1.06)
Column 1: SW1.1, SW13.1, SW25.1, SW37.1, SW49.1, SW61.1, SW73.1, U1.2 (P1.10)
Column 2: SW2.1, SW14.1, SW26.1, SW38.1, SW50.1, SW62.1, SW74.1, U1.3 (P0.03/AIN1)
Column 3: SW3.1, SW15.1, SW27.1, SW39.1, SW51.1, SW63.1, SW75.1, U1.4 (P0.28/AIN4)
Column 4: SW4.1, SW16.1, SW28.1, SW40.1, SW52.1, SW64.1, SW76.1, U1.6 (P1.13)
Column 5: SW5.1, SW17.1, SW29.1, SW41.1, SW53.1, SW65.1, SW77.1, U1.7 (P0.02/AIN0)
Column 6: SW6.1, SW18.1, SW30.1, SW42.1, SW54.1, SW66.1, SW78.1, U1.8 (P0.29/AIN5)
Column 7: SW7.1, SW19.1, SW31.1, SW43.1, SW55.1, SW67.1, SW79.1, U1.9 (P0.31/AIN7)
Column 8: SW8.1, SW20.1, SW32.1, SW44.1, SW56.1, SW68.1, SW80.1, U1.10 (P0.30/AIN6)
Column 9: SW9.1, SW21.1, SW33.1, SW45.1, SW57.1, SW69.1, SW81.1, U1.12 (P0.26)
Column 10: SW10.1, SW22.1, SW34.1, SW46.1, SW58.1, SW70.1, SW82.1, U1.14 (P0.06)
Column 11: SW11.1, SW23.1, SW35.1, SW47.1, SW59.1, SW71.1, SW83.1, U1.16 (P0.08)
Column 12: SW12.1, SW24.1, SW36.1, SW48.1, SW60.1, SW72.1, SW84.1, U1.20 (P0.12)
DATA+: J1.A6 (D+), J1.B6 (D+), U1.31 (USB_D+)
DATA-: J1.A7 (D-), J1.B7 (D-), U1.29 (USB_D-)
DCCH: U1.25 (DCCH)
EXT_VCC: Q2.3 (D)
GND: J1.A1 (GND), J1.S1 (SHIELD), J2.2, J3.2, LED1.3 (VSS), LED2.3 (VSS), LED3.3 (VSS), LED4.3 (VSS), LED5.3 (VSS), LED6.3 (VSS), LED7.3 (VSS), LED8.3 (VSS), LED9.3 (VSS), LED10.3 (VSS), LED11.3 (VSS), LED12.3 (VSS), LED13.3 (VSS), LED14.3 (VSS), LED15.3 (VSS), LED16.3 (VSS), LED17.3 (VSS), LED18.3 (VSS), LED19.3 (VSS), LED20.3 (VSS), LED21.3 (VSS), LED22.3 (VSS), LED23.3 (VSS), LED24.3 (VSS), LED25.3 (VSS), LED26.3 (VSS), LED27.3 (VSS), LED28.3 (VSS), LED29.3 (VSS), LED30.3 (VSS), LED31.3 (VSS), LED32.3 (VSS), LED33.3 (VSS), LED34.3 (VSS), LED35.3 (VSS), LED36.3 (VSS), LED37.3 (VSS), LED38.3 (VSS), LED39.3 (VSS), LED40.3 (VSS), LED41.3 (VSS), LED42.3 (VSS), LED43.3 (VSS), LED44.3 (VSS), LED45.3 (VSS), LED46.3 (VSS), LED47.3 (VSS), LED48.3 (VSS), LED49.3 (VSS), LED50.3 (VSS), LED51.3 (VSS), LED52.3 (VSS), LED53.3 (VSS), LED54.3 (VSS), LED55.3 (VSS), LED56.3 (VSS), LED57.3 (VSS), LED58.3 (VSS), LED59.3 (VSS), LED60.3 (VSS), LED61.3 (VSS), LED62.3 (VSS), LED63.3 (VSS), LED64.3 (VSS), LED65.3 (VSS), LED66.3 (VSS), LED67.3 (VSS), LED68.3 (VSS), LED69.3 (VSS), LED70.3 (VSS), LED71.3 (VSS), LED72.3 (VSS), LED73.3 (VSS), LED74.3 (VSS), LED75.3 (VSS), LED76.3 (VSS), LED77.3 (VSS), LED78.3 (VSS), LED79.3 (VSS), LED80.3 (VSS), LED81.3 (VSS), LED82.3 (VSS), LED83.3 (VSS), LED84.3 (VSS), R1.2, R2.2, R3.2, R5.2, R7.2, R9.2, SW85.2, U1.5 (GND), U1.21 (GND), U1.24 (GND), U2.2 (GND), U3.2 (VSS), U4.1, U4.4, U4.5, U4.7 (GND), U4.9, U4.10, U4.12, U4.13
MISO: U1.30 (P0.17)
MOSI: U1.32 (P0.20)
unnamed: D1.2 (A), SW1.2
unnamed: D2.2 (A), SW2.2
unnamed: D3.2 (A), SW3.2
unnamed: D4.2 (A), SW4.2
unnamed: D5.2 (A), SW5.2
unnamed: D6.2 (A), SW6.2
unnamed: D7.2 (A), SW7.2
unnamed: D8.2 (A), SW8.2
unnamed: D9.2 (A), SW9.2
unnamed: D10.2 (A), SW10.2
unnamed: D11.2 (A), SW11.2
unnamed: D12.2 (A), SW12.2
unnamed: D13.2 (A), SW13.2
unnamed: D14.2 (A), SW14.2
unnamed: D15.2 (A), SW15.2
unnamed: D16.2 (A), SW16.2
unnamed: D17.2 (A), SW17.2
unnamed: D18.2 (A), SW18.2
unnamed: D19.2 (A), SW19.2
unnamed: D20.2 (A), SW20.2
unnamed: D21.2 (A), SW21.2
unnamed: D22.2 (A), SW22.2
unnamed: D23.2 (A), SW23.2
unnamed: D24.2 (A), SW24.2
unnamed: D25.2 (A), SW25.2
unnamed: D26.2 (A), SW26.2
unnamed: D27.2 (A), SW27.2
unnamed: D28.2 (A), SW28.2
unnamed: D29.2 (A), SW29.2
unnamed: D30.2 (A), SW30.2
unnamed: D31.2 (A), SW31.2
unnamed: D32.2 (A), SW32.2
unnamed: D33.2 (A), SW33.2
unnamed: D34.2 (A), SW34.2
unnamed: D35.2 (A), SW35.2
unnamed: D36.2 (A), SW36.2
unnamed: D37.2 (A), SW37.2
unnamed: D38.2 (A), SW38.2
unnamed: D39.2 (A), SW39.2
unnamed: D40.2 (A), SW40.2
unnamed: D41.2 (A), SW41.2
unnamed: D42.2 (A), SW42.2
unnamed: D43.2 (A), SW43.2
unnamed: D44.2 (A), SW44.2
unnamed: D45.2 (A), SW45.2
unnamed: D46.2 (A), SW46.2
unnamed: D47.2 (A), SW47.2
unnamed: D48.2 (A), SW48.2
unnamed: D49.2 (A), SW49.2
unnamed: D50.2 (A), SW50.2
unnamed: D51.2 (A), SW51.2
unnamed: D52.2 (A), SW52.2
unnamed: D53.2 (A), SW53.2
unnamed: D54.2 (A), SW54.2
unnamed: D55.2 (A), SW55.2
unnamed: D56.2 (A), SW56.2
unnamed: D57.2 (A), SW57.2
unnamed: D58.2 (A), SW58.2
unnamed: D59.2 (A), SW59.2
unnamed: D60.2 (A), SW60.2
unnamed: D61.2 (A), SW61.2
unnamed: D62.2 (A), SW62.2
unnamed: D63.2 (A), SW63.2
unnamed: D64.2 (A), SW64.2
unnamed: D65.2 (A), SW65.2
unnamed: D66.2 (A), SW66.2
unnamed: D67.2 (A), SW67.2
unnamed: D68.2 (A), SW68.2
unnamed: D69.2 (A), SW69.2
unnamed: D70.2 (A), SW70.2
unnamed: D71.2 (A), SW71.2
unnamed: D72.2 (A), SW72.2
unnamed: D73.2 (A), SW73.2
unnamed: D74.2 (A), SW74.2
unnamed: D75.2 (A), SW75.2
unnamed: D76.2 (A), SW76.2
unnamed: D77.2 (A), SW77.2
unnamed: D78.2 (A), SW78.2
unnamed: D79.2 (A), SW79.2
unnamed: D80.2 (A), SW80.2
unnamed: D81.2 (A), SW81.2
unnamed: D82.2 (A), SW82.2
unnamed: D83.2 (A), SW83.2
unnamed: D84.2 (A), SW84.2
unnamed: D100.1 (K), Q1.2 (S), U2.1 (VIN), U2.3 (EN)
unnamed: D200.1 (K), R8.1
unnamed: LED1.4 (DIN), U4.3
unnamed: LED1.2 (DOUT), LED2.4 (DIN)
unnamed: LED2.2 (DOUT), LED3.4 (DIN)
unnamed: LED3.2 (DOUT), LED4.4 (DIN)
unnamed: LED4.2 (DOUT), LED5.4 (DIN)
unnamed: LED5.2 (DOUT), LED6.4 (DIN)
unnamed: LED6.2 (DOUT), LED7.4 (DIN)
unnamed: LED7.2 (DOUT), LED8.4 (DIN)
unnamed: LED8.2 (DOUT), LED9.4 (DIN)
unnamed: LED9.2 (DOUT), LED10.4 (DIN)
unnamed: LED10.2 (DOUT), LED11.4 (DIN)
unnamed: LED11.2 (DOUT), LED12.4 (DIN)
unnamed: LED12.2 (DOUT), LED13.4 (DIN)
unnamed: LED13.2 (DOUT), LED14.4 (DIN)
unnamed: LED14.2 (DOUT), LED15.4 (DIN)
unnamed: LED15.2 (DOUT), LED16.4 (DIN)
unnamed: LED16.2 (DOUT), LED17.4 (DIN)
unnamed: LED17.2 (DOUT), LED18.4 (DIN)
unnamed: LED18.2 (DOUT), LED19.4 (DIN)
unnamed: LED19.2 (DOUT), LED20.4 (DIN)
unnamed: LED20.2 (DOUT), LED21.4 (DIN)
unnamed: LED21.2 (DOUT), LED22.4 (DIN)
unnamed: LED22.2 (DOUT), LED23.4 (DIN)
unnamed: LED23.2 (DOUT), LED24.4 (DIN)
unnamed: LED24.2 (DOUT), LED25.4 (DIN)
unnamed: LED25.2 (DOUT), LED26.4 (DIN)
unnamed: LED26.2 (DOUT), LED27.4 (DIN)
unnamed: LED27.2 (DOUT), LED28.4 (DIN)
unnamed: LED28.2 (DOUT), LED29.4 (DIN)
unnamed: LED29.2 (DOUT), LED30.4 (DIN)
unnamed: LED30.2 (DOUT), LED31.4 (DIN)
unnamed: LED31.2 (DOUT), LED32.4 (DIN)
unnamed: LED32.2 (DOUT), LED33.4 (DIN)
unnamed: LED33.2 (DOUT), LED34.4 (DIN)
unnamed: LED34.2 (DOUT), LED35.4 (DIN)
unnamed: LED35.2 (DOUT), LED36.4 (DIN)
unnamed: LED36.2 (DOUT), LED37.4 (DIN)
unnamed: LED37.2 (DOUT), LED38.4 (DIN)
unnamed: LED38.2 (DOUT), LED39.4 (DIN)
unnamed: LED39.2 (DOUT), LED40.4 (DIN)
unnamed: LED40.2 (DOUT), LED41.4 (DIN)
unnamed: LED41.2 (DOUT), LED42.4 (DIN)
unnamed: LED42.2 (DOUT), LED43.4 (DIN)
unnamed: LED43.2 (DOUT), LED44.4 (DIN)
unnamed: LED44.2 (DOUT), LED45.4 (DIN)
unnamed: LED45.2 (DOUT), LED46.4 (DIN)
unnamed: LED46.2 (DOUT), LED47.4 (DIN)
unnamed: LED47.2 (DOUT), LED48.4 (DIN)
unnamed: LED48.2 (DOUT), LED49.4 (DIN)
unnamed: LED49.2 (DOUT), LED50.4 (DIN)
unnamed: LED50.2 (DOUT), LED51.4 (DIN)
unnamed: LED51.2 (DOUT), LED52.4 (DIN)
unnamed: LED52.2 (DOUT), LED53.4 (DIN)
unnamed: LED53.2 (DOUT), LED54.4 (DIN)
unnamed: LED54.2 (DOUT), LED55.4 (DIN)
unnamed: LED55.2 (DOUT), LED56.4 (DIN)
unnamed: LED56.2 (DOUT), LED57.4 (DIN)
unnamed: LED57.2 (DOUT), LED58.4 (DIN)
unnamed: LED58.2 (DOUT), LED59.4 (DIN)
unnamed: LED59.2 (DOUT), LED60.4 (DIN)
unnamed: LED60.2 (DOUT), LED61.4 (DIN)
unnamed: LED61.2 (DOUT), LED62.4 (DIN)
unnamed: LED62.2 (DOUT), LED63.4 (DIN)
unnamed: LED63.2 (DOUT), LED64.4 (DIN)
unnamed: LED64.2 (DOUT), LED65.4 (DIN)
unnamed: LED65.2 (DOUT), LED66.4 (DIN)
unnamed: LED66.2 (DOUT), LED67.4 (DIN)
unnamed: LED67.2 (DOUT), LED68.4 (DIN)
unnamed: LED68.2 (DOUT), LED69.4 (DIN)
unnamed: LED69.2 (DOUT), LED70.4 (DIN)
unnamed: LED70.2 (DOUT), LED71.4 (DIN)
unnamed: LED71.2 (DOUT), LED72.4 (DIN)
unnamed: LED72.2 (DOUT), LED73.4 (DIN)
unnamed: LED73.2 (DOUT), LED74.4 (DIN)
unnamed: LED74.2 (DOUT), LED75.4 (DIN)
unnamed: LED75.2 (DOUT), LED76.4 (DIN)
unnamed: LED76.2 (DOUT), LED77.4 (DIN)
unnamed: LED77.2 (DOUT), LED78.4 (DIN)
unnamed: LED78.2 (DOUT), LED79.4 (DIN)
unnamed: LED79.2 (DOUT), LED80.4 (DIN)
unnamed: LED80.2 (DOUT), LED81.4 (DIN)
unnamed: LED81.2 (DOUT), LED82.4 (DIN)
unnamed: LED82.2 (DOUT), LED83.4 (DIN)
unnamed: LED83.2 (DOUT), LED84.4 (DIN)
unnamed: U1.11 (P0.00/XL1), X1.2
unnamed: U1.13 (P0.01/XL2), X1.1
unnamed: R5.1, U3.5 (PROG)
unnamed: R8.2, U3.1 (STAT)
POWER_PIN: Q2.1 (G), R9.1, U1.17 (P1.09)
PROG: U1.15 (P0.05/AIN3)
RESET: SW85.1, TP1.1, U1.26 (P0.18/RESET); also elsewhere on the board
RGB LEDs: U1.1 (P1.11), U4.2
Row 1: D1.1 (K), D2.1 (K), D3.1 (K), D4.1 (K), D5.1 (K), D6.1 (K), D7.1 (K), D8.1 (K), D9.1 (K), D10.1 (K), D11.1 (K), D12.1 (K), U1.22 (P0.07)
Row 2: D13.1 (K), D14.1 (K), D15.1 (K), D16.1 (K), D17.1 (K), D18.1 (K), D19.1 (K), D20.1 (K), D21.1 (K), D22.1 (K), D23.1 (K), D24.1 (K), U1.43 (P0.10/NFC2)
Row 3: D25.1 (K), D26.1 (K), D27.1 (K), D28.1 (K), D29.1 (K), D30.1 (K), D31.1 (K), D32.1 (K), D33.1 (K), D34.1 (K), D35.1 (K), D36.1 (K), U1.41 (P0.09/NFC1)
Row 4: D37.1 (K), D38.1 (K), D39.1 (K), D40.1 (K), D41.1 (K), D42.1 (K), D43.1 (K), D44.1 (K), D45.1 (K), D46.1 (K), D47.1 (K), D48.1 (K), U1.40 (P1.04)
Row 5: D49.1 (K), D50.1 (K), D51.1 (K), D52.1 (K), D53.1 (K), D54.1 (K), D55.1 (K), D56.1 (K), D57.1 (K), D58.1 (K), D59.1 (K), D60.1 (K), U1.38 (P1.02)
Row 6: D61.1 (K), D62.1 (K), D63.1 (K), D64.1 (K), D65.1 (K), D66.1 (K), D67.1 (K), D68.1 (K), D69.1 (K), D70.1 (K), D71.1 (K), D72.1 (K), U1.36 (P1.00)
Row 7: D73.1 (K), D74.1 (K), D75.1 (K), D76.1 (K), D77.1 (K), D78.1 (K), D79.1 (K), D80.1 (K), D81.1 (K), D82.1 (K), D83.1 (K), D84.1 (K), U1.34 (P0.22)
SCK: U1.28 (P0.15)
SCL: U1.35 (P0.24)
SDA: U1.33 (P0.13)
SWC: J2.4, U1.39 (SWDCLK)
SWD: J2.3, U1.37 (SWDIO)
VBAT: J3.1, Q1.3 (D), R6.1, U3.3 (VBAT)
VBUS: D100.2 (A), D200.2 (A), J1.A4 (VBUS), LED1.1 (VDD), LED2.1 (VDD), LED3.1 (VDD), LED4.1 (VDD), LED5.1 (VDD), LED6.1 (VDD), LED7.1 (VDD), LED8.1 (VDD), LED9.1 (VDD), LED10.1 (VDD), LED11.1 (VDD), LED12.1 (VDD), LED13.1 (VDD), LED14.1 (VDD), LED15.1 (VDD), LED16.1 (VDD), LED17.1 (VDD), LED18.1 (VDD), LED19.1 (VDD), LED20.1 (VDD), LED21.1 (VDD), LED22.1 (VDD), LED23.1 (VDD), LED24.1 (VDD), LED25.1 (VDD), LED26.1 (VDD), LED27.1 (VDD), LED28.1 (VDD), LED29.1 (VDD), LED30.1 (VDD), LED31.1 (VDD), LED32.1 (VDD), LED33.1 (VDD), LED34.1 (VDD), LED35.1 (VDD), LED36.1 (VDD), LED37.1 (VDD), LED38.1 (VDD), LED39.1 (VDD), LED40.1 (VDD), LED41.1 (VDD), LED42.1 (VDD), LED43.1 (VDD), LED44.1 (VDD), LED45.1 (VDD), LED46.1 (VDD), LED47.1 (VDD), LED48.1 (VDD), LED49.1 (VDD), LED50.1 (VDD), LED51.1 (VDD), LED52.1 (VDD), LED53.1 (VDD), LED54.1 (VDD), LED55.1 (VDD), LED56.1 (VDD), LED57.1 (VDD), LED58.1 (VDD), LED59.1 (VDD), LED60.1 (VDD), LED61.1 (VDD), LED62.1 (VDD), LED63.1 (VDD), LED64.1 (VDD), LED65.1 (VDD), LED66.1 (VDD), LED67.1 (VDD), LED68.1 (VDD), LED69.1 (VDD), LED70.1 (VDD), LED71.1 (VDD), LED72.1 (VDD), LED73.1 (VDD), LED74.1 (VDD), LED75.1 (VDD), LED76.1 (VDD), LED77.1 (VDD), LED78.1 (VDD), LED79.1 (VDD), LED80.1 (VDD), LED81.1 (VDD), LED82.1 (VDD), LED83.1 (VDD), LED84.1 (VDD), Q1.1 (G), R1.1, U1.27 (VBUS), U3.4 (VDD), U4.14 (VCC)
nRF_VDD: J2.1, Q2.2 (S), U1.19 (VDD), U1.23 (VDDH), U2.5 (VOUT)

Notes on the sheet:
LiPo Charging
RProg = 1000/iBat iBat in amps RProg iBAT 10k 100mA 5k 200mA 2.5k 400mA 2k 500mA 1.25k 800mA
Power and Filtering
Battery monitor
E73-2G4M08S1C pins: P0.02 P0.03 P0.04 P0.05 P0.06 P0.07 P0.08 P0.09 P0.10 P0.12 P0.13 P0.15 P0.17 P0.18 P0.20 P0.22 P0.24 P0.26 P0.28 P0.29 P0.30 P0.31 P1.00 P1.02 P1.04 P1.06 P1.09 P1.10 P1.11 P1.13
Feather pins: P1.15 LED1 x P1.10 LED2 P0.15 BTN1 P0.19 BTN2 x P0.16 NEOPIXEL x P0.08 RX P0.06 TX P1.02 DFU P0.18 RESET

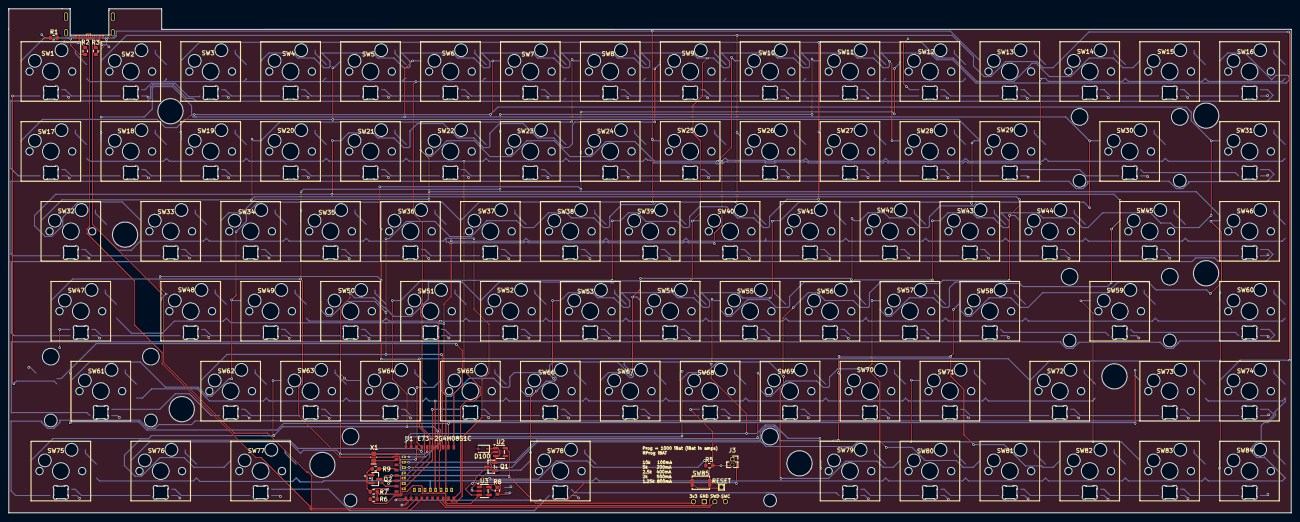
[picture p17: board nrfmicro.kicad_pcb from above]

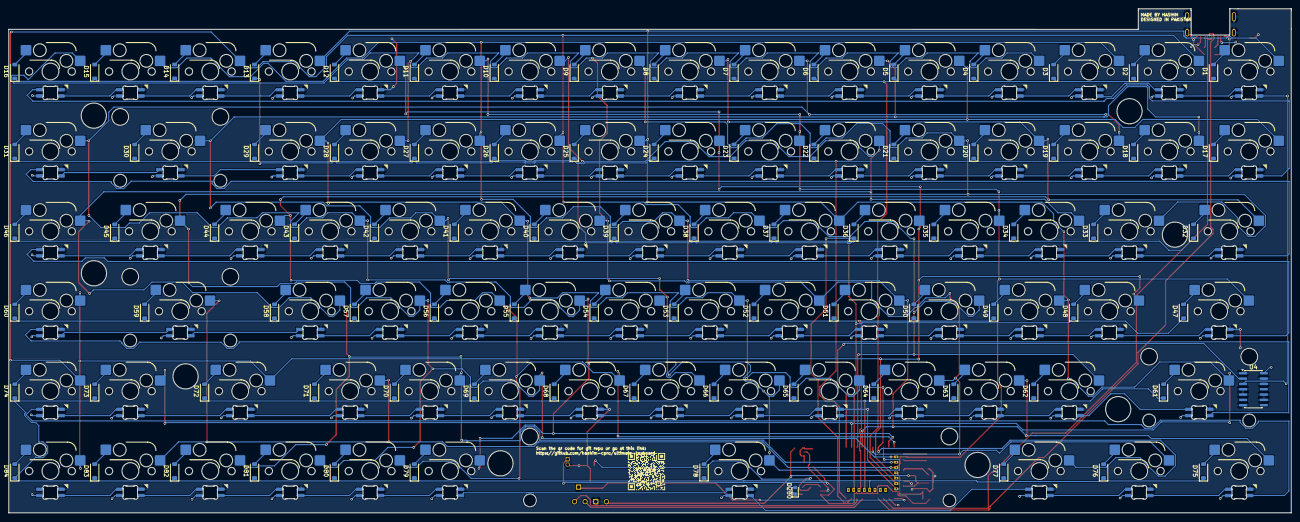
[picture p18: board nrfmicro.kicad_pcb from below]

Board: 2 copper layers, 305.8 x 120.2 mm, 274 parts (86 on the bottom side), 207 nets.

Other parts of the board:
RESET: TestPoint; TestPoint_THTPad_1.0x1.0mm_Drill0.5mm

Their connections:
RESET: RESET.1; also elsewhere on the board

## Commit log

2026-09-09 Switch to official ZMK reusable workflow with root zephyr module
2026-09-09 feat(firmware): migrate board to Zephyr HWMv2 structure with ZMK variant
2026-09-09 fix(dts): remove keys.h and bt.h from board DTS to avoid RC() macro collision
2026-09-26 add wiring diagram + assembly instructions
